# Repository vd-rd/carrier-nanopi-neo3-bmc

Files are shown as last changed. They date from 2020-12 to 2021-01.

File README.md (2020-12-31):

# NanoPi Neo 3 Carrier board

This board is designed to enhance the FriendlyElec NanoPi Neo 3 board with features suitable for a "server" style deployment. It uses a ESP32 as a BMC.

Features provided:
 - RTC clock 
 - Wired Ethernet interface
 - Gated power supply

## Motivation

Most SBC platforms lack the features needed for a rack style deployment where you can power cycle the board or get a remote console to debug what went wrong.
The ESP32 uC is fairly popular, but the reason behind selecting it to act as a BMC is that is one of the cheapest uCs equipped with a Ethernet PHY.

## Hardware overview
 (Diagram)

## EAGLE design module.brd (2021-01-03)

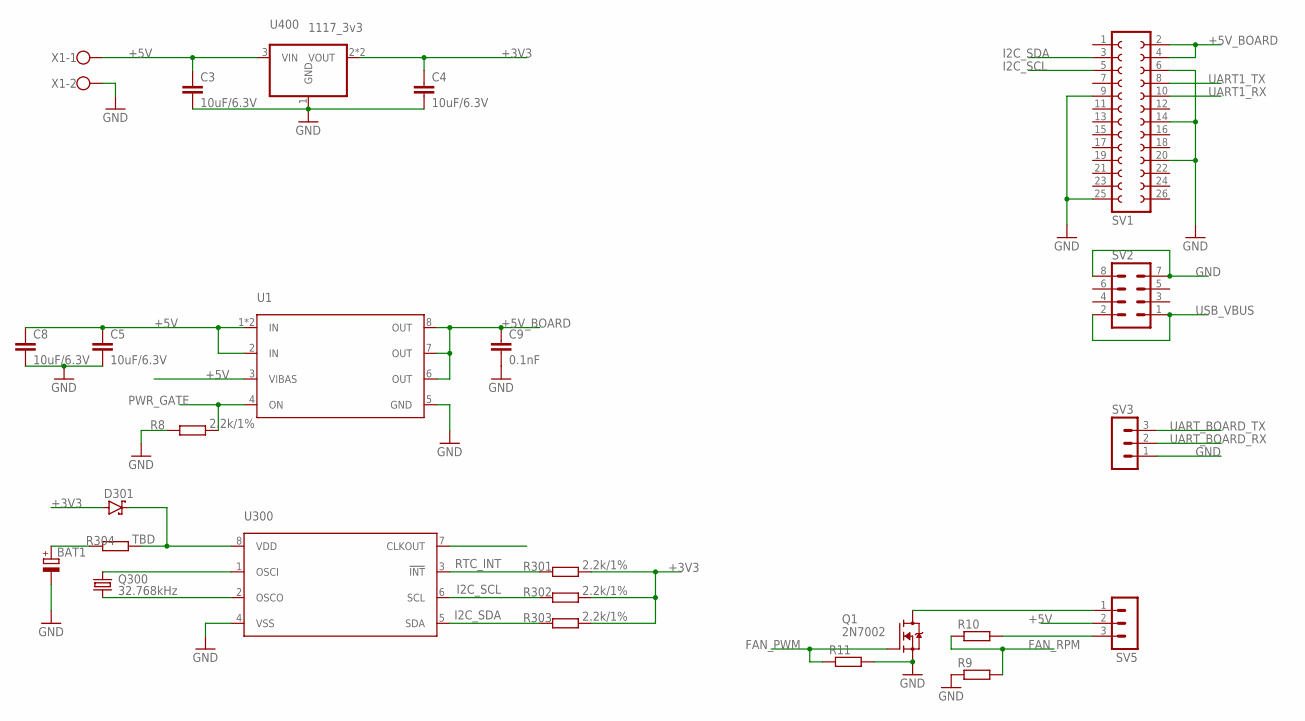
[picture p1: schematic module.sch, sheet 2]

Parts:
BAT1: DCK-3R3E224U-E; 621
C3, C4: 10uF/6.3V; C1206
C5, C8: 10uF/6.3V; C0603
C9: 0.1nF; C0603
D301: NSR0320; SOD323
Q1: 2N7002; SOT95P240X110-3
Q300: 32.768kHz; 3215
R8, R301, R302, R303: 2.2k/1%; R0603
R9, R10, R11: R-EU_R0603; R0603
R304: TBD; R0603
SV1: FE13-2
SV2: MA04-2
SV3: MA03-1FEMALE; MA03-1
SV5: MA03-1
U1: DML10M8LDS; SON65P300X300X80-9T160X240N
U300: PCF85063ATT; SOP65P490X110-8N
U400: 1117_3v3; SOT230P700X180-4
X1: W237-102; EBBA

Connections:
+3V3: C4.1, D301.A, R301.2, R302.2, R303.2, U400.2 (VOUT), U400.4 (VOUT); also elsewhere on the board
+5V: C3.1, C5.1, C8.1, SV5.2, U1.1 (IN), U1.2 (IN), U1.3 (VIBAS), U1.9 (IN), U400.3 (VIN), X1.1
+5V_BOARD: C9.1, SV1.2, SV1.4, U1.6 (OUT), U1.7 (OUT), U1.8 (OUT)
FAN_PWM: Q1.1 (G), R11.1; also elsewhere on the board
FAN_RPM: R9.2, R10.1; also elsewhere on the board
GND: BAT1.-, C3.2, C4.2, C5.2, C8.2, C9.2, Q1.2 (S), R8.1, R9.1, R11.2, SV1.6, SV1.9, SV1.14, SV1.20, SV1.25, SV2.7, SV2.8, SV3.1, U1.5 (GND), U300.4 (VSS), U400.1 (GND), X1.2; also elsewhere on the board
I2C_SCL: R302.1, SV1.5, U300.6 (SCL); also elsewhere on the board
I2C_SDA: R303.1, SV1.3, U300.5 (SDA); also elsewhere on the board
unnamed: Q1.3 (D), SV5.1
unnamed: R10.2, SV5.3
unnamed: Q300.1, U300.2 (OSCO)
unnamed: Q300.2, U300.1 (OSCI)
unnamed: BAT1.+, R304.1
unnamed: D301.K (C), R304.2, U300.8 (VDD)
PWR_GATE: R8.2, U1.4 (ON); also elsewhere on the board
RTC_INT: R301.1, U300.3 (!INT)
UART1_RX: SV1.10
UART1_TX: SV1.8
UART_BOARD_RX: SV3.2; also elsewhere on the board
UART_BOARD_TX: SV3.3; also elsewhere on the board
USB_VBUS: SV2.1, SV2.2

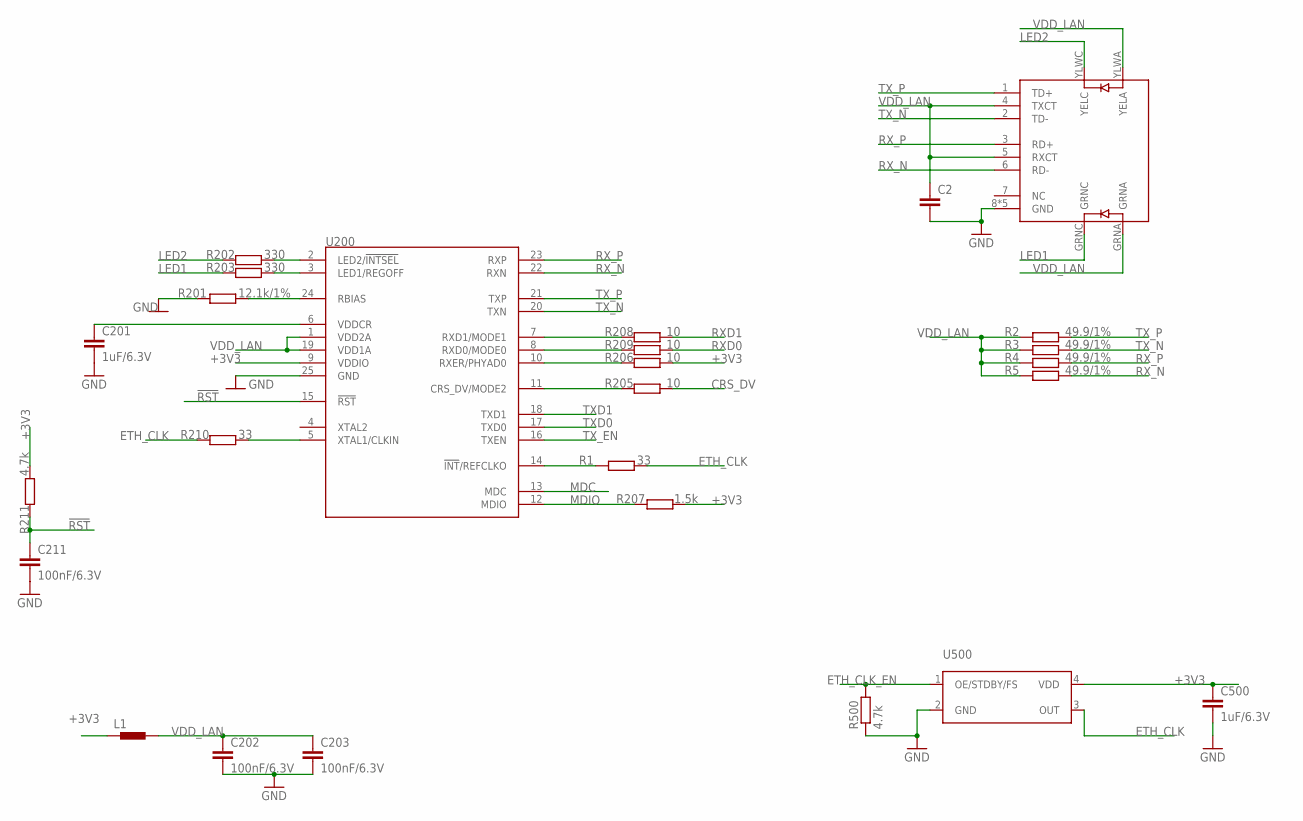
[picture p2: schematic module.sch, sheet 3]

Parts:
C2: C-EUC0603; C0603
C201, C500: 1uF/6.3V; C0603
C202, C203, C211: 100nF/6.3V; C0603
J1: ARJM11X1009XXXXX; LAYOUT1-HORIZ-LEDS
L1: FER-0603; FER0603
R1, R210: 33; R0603
R2, R3, R4, R5: 49.9/1%; R0603
R201: 12.1k/1%; R0603
R202, R203: 330; R0603
R205, R206, R208, R209: 10; R0603
R207: 1.5k; R0603
R211, R500: 4.7k; R0603
U200: LAN8720A; QFN50P400X400X100-25T250N
U500: DSC61XXC; DIODFN250X200X89-4N

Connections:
!RST: C211.1, R211.1, U200.15 (!RST)
+3V3: C500.1, L1.1, R206.2, R207.2, R211.2, U200.9 (VDDIO), U500.4 (VDD); also elsewhere on the board
CRS_DV: R205.2; also elsewhere on the board
ETH_CLK: R1.2, R210.1, U500.3 (OUT); also elsewhere on the board
ETH_CLK_EN: R500.2, U500.1 (OE/STDBY/FS); also elsewhere on the board
GND: C2.2, C201.2, C202.2, C203.2, C211.2, C500.2, J1.8 (GND), J1.P$1 (GND), J1.P$2 (GND), J1.P$3 (GND), J1.P$4 (GND), R201.1, R500.1, U200.25 (GND), U500.2 (GND); also elsewhere on the board
LED1: J1.GRNC, R203.1
LED2: J1.YLWC (YELC), R202.1
MDC: U200.13 (MDC); also elsewhere on the board
MDIO: R207.1, U200.12 (MDIO); also elsewhere on the board
unnamed: R208.1, U200.7 (RXD1/MODE1)
unnamed: R210.2, U200.5 (XTAL1/CLKIN)
unnamed: C201.1, U200.6 (VDDCR)
unnamed: R202.2, U200.2 (LED2/!INTSEL)
unnamed: R203.2, U200.3 (LED1/REGOFF)
unnamed: R209.1, U200.8 (RXD0/MODE0)
unnamed: R201.2, U200.24 (RBIAS)
unnamed: R206.1, U200.10 (RXER/PHYAD0)
unnamed: R205.1, U200.11 (CRS_DV/MODE2)
unnamed: R1.1, U200.14 (!INT!/REFCLKO)
RXD0: R209.2; also elsewhere on the board
RXD1: R208.2; also elsewhere on the board
RX_N: J1.6 (RD-), R5.2, U200.22 (RXN)
RX_P: J1.3 (RD+), R4.2, U200.23 (RXP)
TXD0: U200.17 (TXD0); also elsewhere on the board
TXD1: U200.18 (TXD1); also elsewhere on the board
TX_EN: U200.16 (TXEN); also elsewhere on the board
TX_N: J1.2 (TD-), R3.2, U200.20 (TXN)
TX_P: J1.1 (TD+), R2.2, U200.21 (TXP)
VDD_LAN: C2.1, C202.1, C203.1, J1.4 (TXCT), J1.5 (RXCT), J1.GRNA, J1.YLWA (YELA), L1.2, R2.1, R3.1, R4.1, R5.1, U200.1 (VDD2A), U200.19 (VDD1A)

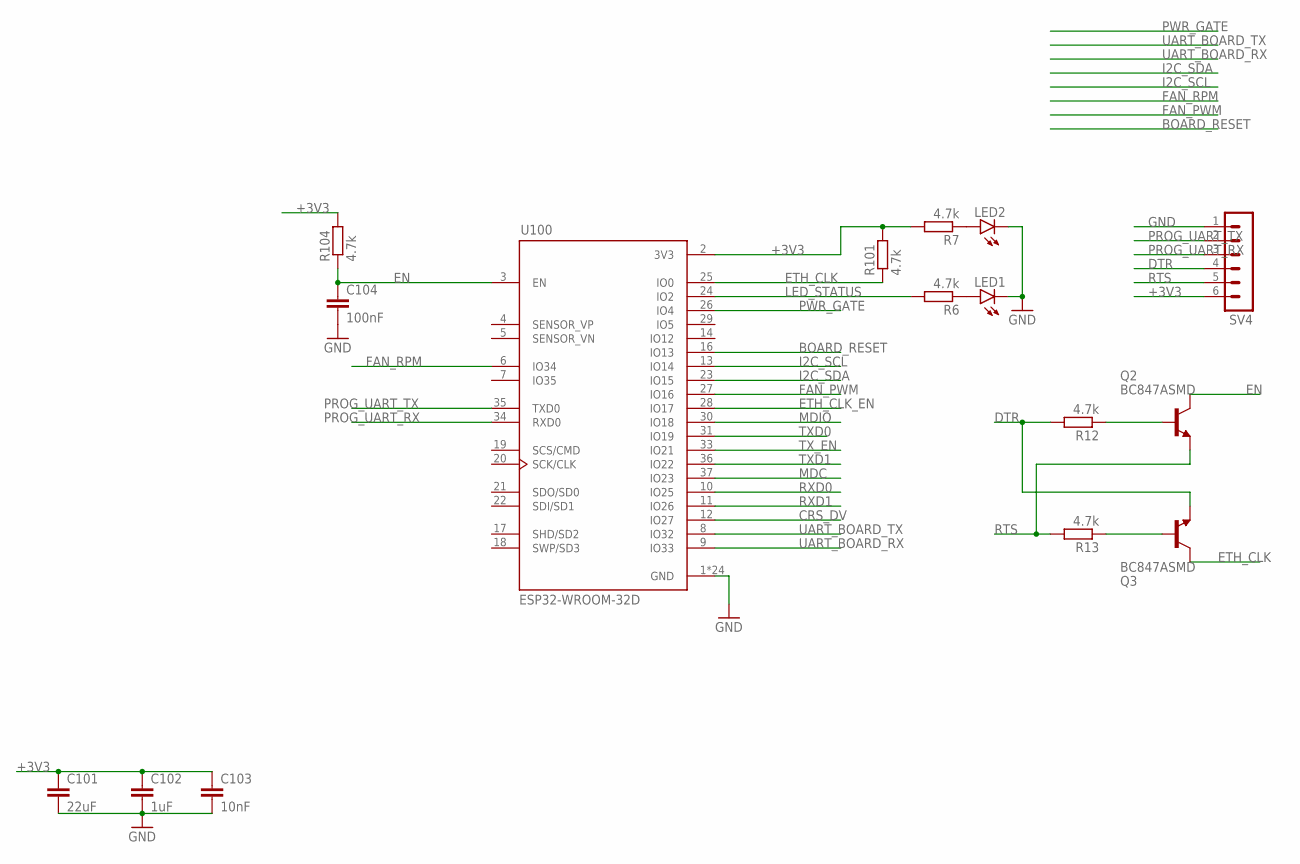
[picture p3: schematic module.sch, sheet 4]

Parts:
C101: 22uF; C1206
C102: 1uF; C0603
C103: 10nF; C0603
C104: 100nF; C0603
LED1, LED2: LEDCHIP-LED0805; CHIP-LED0805
Q2, Q3: BC847ASMD; SOT23
R6, R7, R12, R13, R101, R104: 4.7k; R0603
SV4: CONN-1X6; MA06-1
U100: ESP32-WROOM-32D; MODULE_ESP32-WROOM-32D

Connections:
+3V3: C101.1, C102.1, C103.1, R7.2, R101.2, R104.2, SV4.6, U100.2 (3V3); also elsewhere on the board
BOARD_RESET: U100.16 (IO13)
CRS_DV: U100.12 (IO27); also elsewhere on the board
DTR: Q3.2 (E), R12.2, SV4.4
EN: C104.1, Q2.3 (C), R104.1, U100.3 (EN)
ETH_CLK: Q3.3 (C), R101.1, U100.25 (IO0); also elsewhere on the board
ETH_CLK_EN: U100.28 (IO17); also elsewhere on the board
FAN_PWM: U100.27 (IO16); also elsewhere on the board
FAN_RPM: U100.6 (IO34); also elsewhere on the board
GND: C101.2, C102.2, C103.2, C104.2, LED1.C, LED2.C, SV4.1, U100.1 (GND), U100.15 (GND), U100.38 (GND), U100.39_1 (GND), U100.39_2 (GND), U100.39_3 (GND), U100.39_4 (GND), U100.39_5 (GND), U100.39_6 (GND), U100.39_7 (GND), U100.39_8 (GND), U100.39_9 (GND), U100.39_10 (GND), U100.39_11 (GND), U100.39_12 (GND), U100.39_13 (GND), U100.39_14 (GND), U100.39_15 (GND), U100.39_16 (GND), U100.39_17 (GND), U100.39_18 (GND), U100.39_19 (GND), U100.39_20 (GND), U100.39_21 (GND); also elsewhere on the board
I2C_SCL: U100.13 (IO14); also elsewhere on the board
I2C_SDA: U100.23 (IO15); also elsewhere on the board
LED_STATUS: R6.2, U100.24 (IO2)
MDC: U100.37 (IO23); also elsewhere on the board
MDIO: U100.30 (IO18); also elsewhere on the board
unnamed: LED1.A, R6.1
unnamed: LED2.A, R7.1
unnamed: Q2.1 (B), R12.1
unnamed: Q3.1 (B), R13.1
PROG_UART_RX: SV4.3, U100.34 (RXD0)
PROG_UART_TX: SV4.2, U100.35 (TXD0)
PWR_GATE: U100.26 (IO4); also elsewhere on the board
RTS: Q2.2 (E), R13.2, SV4.5
RXD0: U100.10 (IO25); also elsewhere on the board
RXD1: U100.11 (IO26); also elsewhere on the board
TXD0: U100.31 (IO19); also elsewhere on the board
TXD1: U100.36 (IO22); also elsewhere on the board
TX_EN: U100.33 (IO21); also elsewhere on the board
UART_BOARD_RX: U100.9 (IO33); also elsewhere on the board
UART_BOARD_TX: U100.8 (IO32); also elsewhere on the board

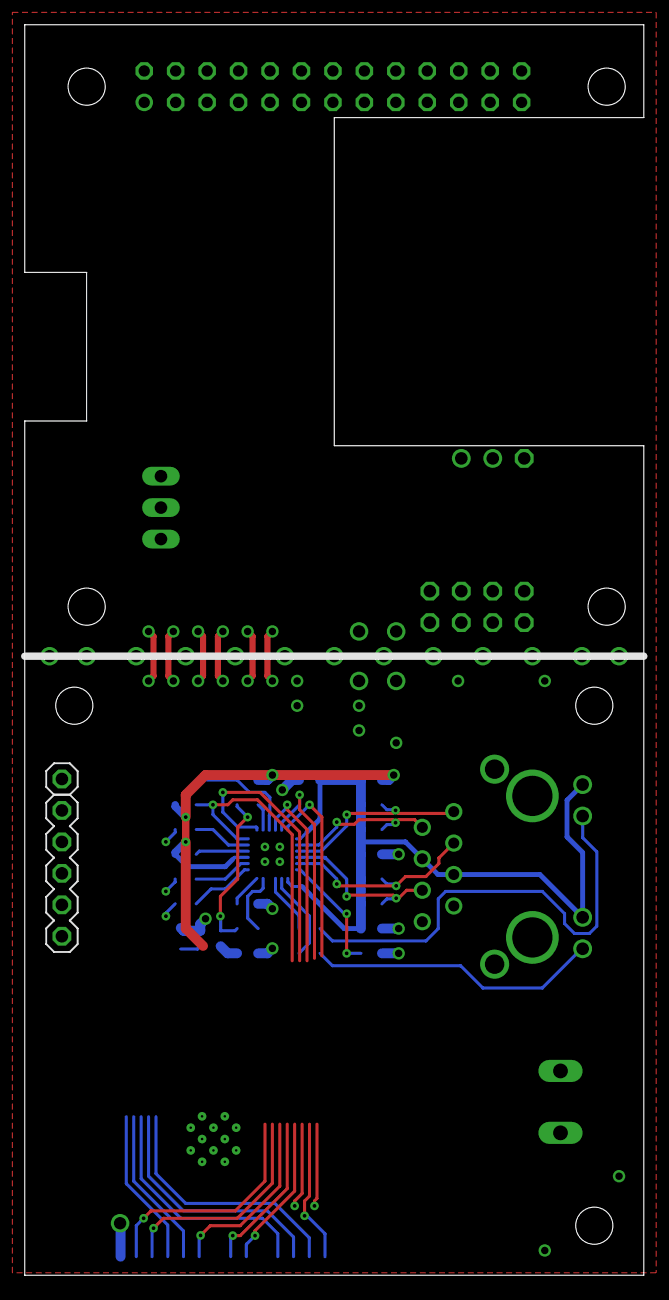
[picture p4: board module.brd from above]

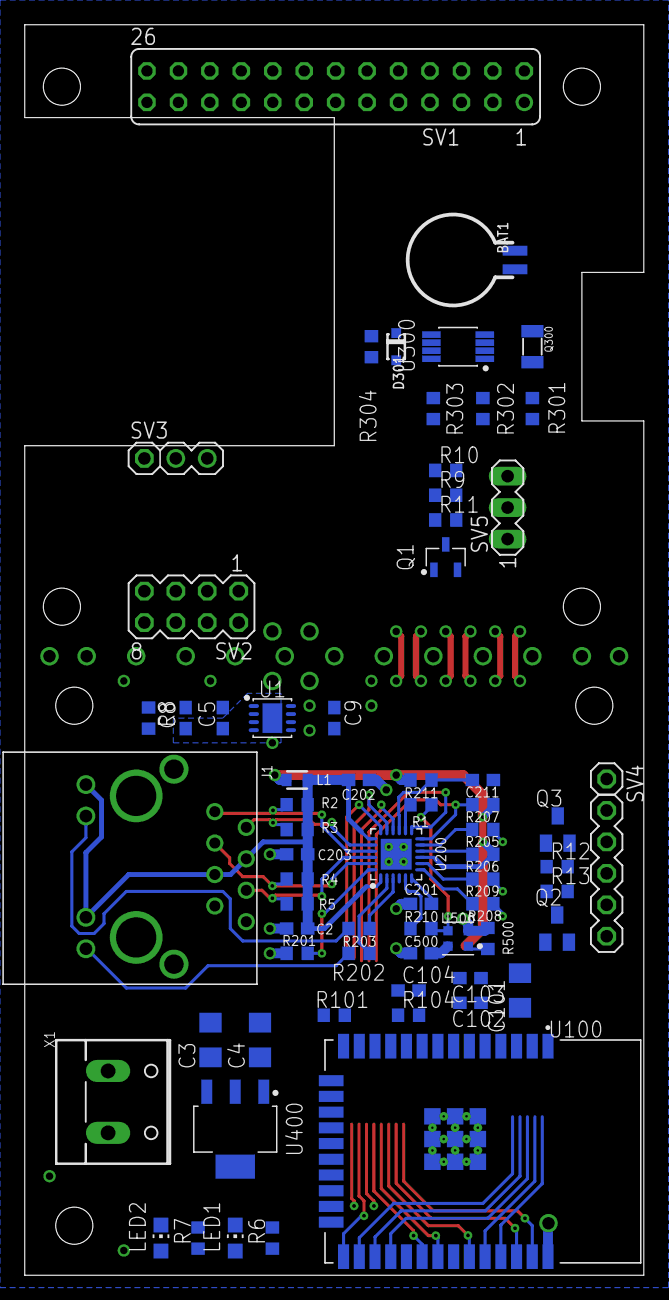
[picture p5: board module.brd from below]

Board: 2 copper layers, 50.0 x 101.0 mm, 67 parts (67 on the bottom side), 57 nets.

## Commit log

2020-12-05 project: add initial board
    [module.brd, module.sch]
2020-12-08 project: add rtc
    [module.brd, module.sch]
2020-12-08 project: add ldo
    [module.brd, module.sch]
2020-12-29 project: change rj45 with integrated magnetics
    [module.brd, module.sch]
2020-12-29 schematic: complete ethernet phy
    [module.brd, module.sch]
2020-12-29 layout: improve component placement
    [module.brd, module.sch]
2020-12-30 project: update readme
    [module.brd, module.sch]
2020-12-31 layout: more routing
    [module.brd]
2020-12-31 project: relayout
    [module.brd, module.sch]
2021-01-02 schematic: add signal section
    [module.brd, module.sch]
2021-01-03 board: add program header
    [module.brd, module.sch]
2021-01-03 project: add fan controller
    [module.brd, module.sch]
2021-01-03 project: route some signals
    [module.brd, module.sch]
